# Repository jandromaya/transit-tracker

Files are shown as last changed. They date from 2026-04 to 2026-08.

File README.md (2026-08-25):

# transit-tracker
This is a personal transit tracker project for CTA buses and trains.

Status: v1 complete!

[Video of v1](./documentation/video.mov)

## Requirements

**Hardware**

2 64x32 LED matrices

Power supply

Connector (right now need the special one for the matrix, soon just a USB-C)

You also need to get the PCB. Using the gerber files in this repo, you can get the PCB manufactured at your preferred PCB manufacturer (I used PCBWay).

## Installing/Building

(These instructions reflect the set-up process as of August 24, 2026.)

### Getting API Keys

Before you start connecting or building anything, you need to have API keys for CTA trains and buses. You can get those here:

Buses: https://ctabustracker.com/account

Trains: https://www.transitchicago.com/developers/traintrackerapply/

Once you have your keys, pull this repo. Inside the `include` folder, make a `secrets.h` file and place your keys in there, like this:

```
#ifndef SECRETS_H
#define SECRETS_H

#define TRAIN_TRACKER_API_KEY "Your key here"
#define BUS_TRACKER_API_KEY "Your keky here"

#endif
```

Now you're ready to build

### Building the tracker

1. Connect LED matrices together with HUB75 cable

2. Connect the PCB to a computer and flash the PCB

   1. Open VS Code, navigate to the project folder, and run idf.py flash

3. Set the tracker configuration

   1. Run idf.py menuconfig from the project folder

   2. In the menuconfig menu, navigate as follows:

      1. Component config->WiFi STA Configuration

         1. Check connect using wifi
         2. Set WiFi SSID and password

      2. Component config->HUB75 RGB LED Matrix Driver

         1. Go to Board Preset and check Manual Pin Configuration

         2. Go to Panel Settings and set the following settings:

            1. Panel Width: 64 (pixels)
            2. Panel Height: 32 (pixels)
            3. Minimum Refresh Rate: 60 (Hz)
            4. Default Brightness: 128

         3. Go to Multi Panel Layout and set the following settings:

            1. Layout Rows: 1
            2. Layour Columns: 2
            3. Layout Type (Horizonal (Single Row))

         4. Go to Pin Configuration and set it as follows:

            ```
            4 - R1
            5 - G1
            6 - B1
            7 - R2
            15 - G2
            16 - B2
            17 - A
            18 - B
            14 - C
            13 - D
            -1 - E
            11 - LAT
            10 - OE
            9 - CLK
            ```

      3. Component config->Transit Tracker Configuration

         1. Check connect using wifi
         2. Check enable bus tracking if you want to track buses
         3. Check enable train tracking if you want to track trains
         4. Hit enter on bus routes to track, and enter the numbers of the buses you want to track
            1. i.e., if you want to track the 1 and the 7, type in `1,7` with no spaces just like shown
         5. Hit enter on bus stop IDs to track, and enter the number of the stop IDs you want to track
            1. i.e., if you want to track stop 68 and stop 1583, type in `68,1583` with no spaces as shown
         6. Hit enter on "Max number of bus predictions to receive," and enter the maximum number of bus predictions you want to display
            1. I recommend 6 or 9
         7. Hit enter on train stop IDs to track, and enter the number of the stop IDs you want to track
            1. i.e., if you want to track the Roosevelt and the Jackson stops, type in `41400,40070` with no spaces as shown
         8. Hit enter on "Max number of train predictions to receive," and enter the maximum number of train predictions you want to display
            1. I recommend 6 or 9

4. Connect the PCB to the matrices with the HUB75

   1. Note: the HUB75 header in v1 of the board is wired wrong, so you have to pull the header pins to the opposite side of the board for it to work. I plan to update the board so this is no longer an issue.

5. Connect the matrices' power leads to the screw terminals on the PCB

   1. Power is closest to the HUB75 header
   2. GND is the other terminal

6. Print the enclosure

   1. Files in 3dprinting folder of this repo

7. Screw PCB to the thin part of the enclosure

   1. There are little holes for screws to go through on both the thin part of the enclosure and the PCB
   2. With v1 of the enclosure/board, the PCB ends up a little tilted when you do this. This is something I plan to fix with the next version

8. Place both parts of the enclosure on top of the LED matrices, and screw them together using the screws that came with the LED matrices

9. Connect the train tracker to wall power using a USB cable

10. Watch your trains/buses go!

### Libraries/Skills used

C, C++, ESP IDF/FreeRTOS, LVGL, PCB Design, CAD (Autodesk Fusion), 3D Printing

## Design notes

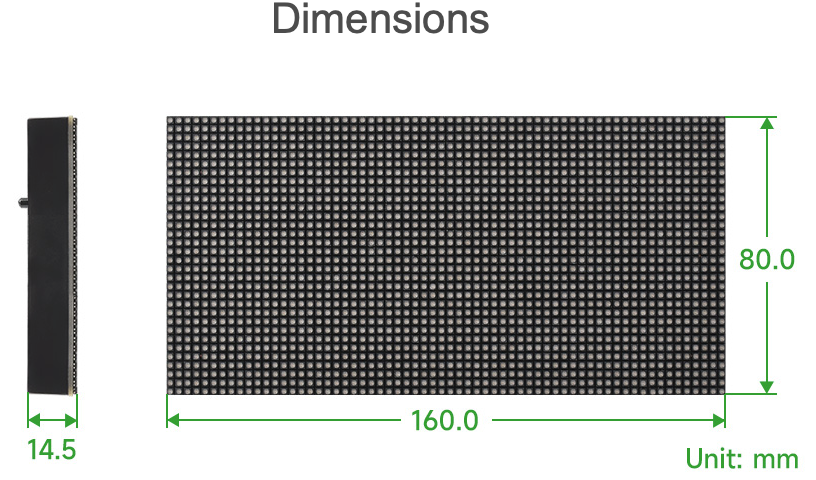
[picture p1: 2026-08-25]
documentation/images/2AUG25_5.JPG.png

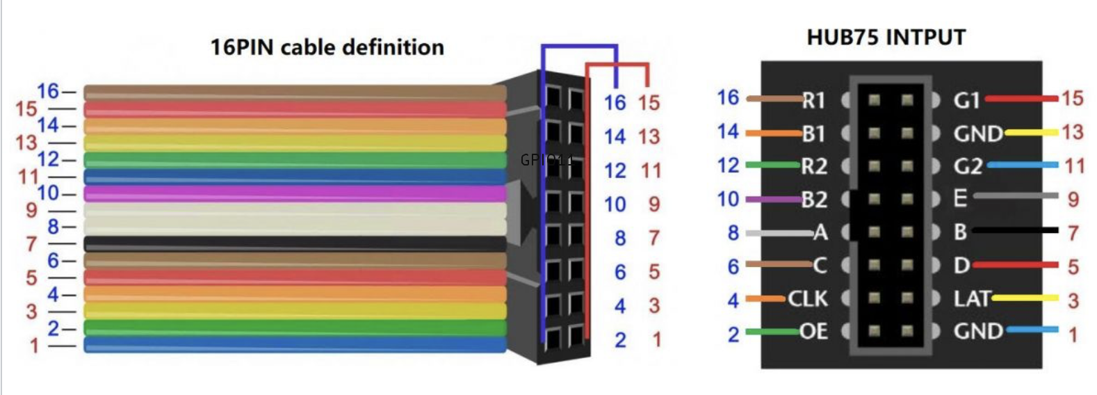
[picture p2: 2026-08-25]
documentation/images/hub75.png

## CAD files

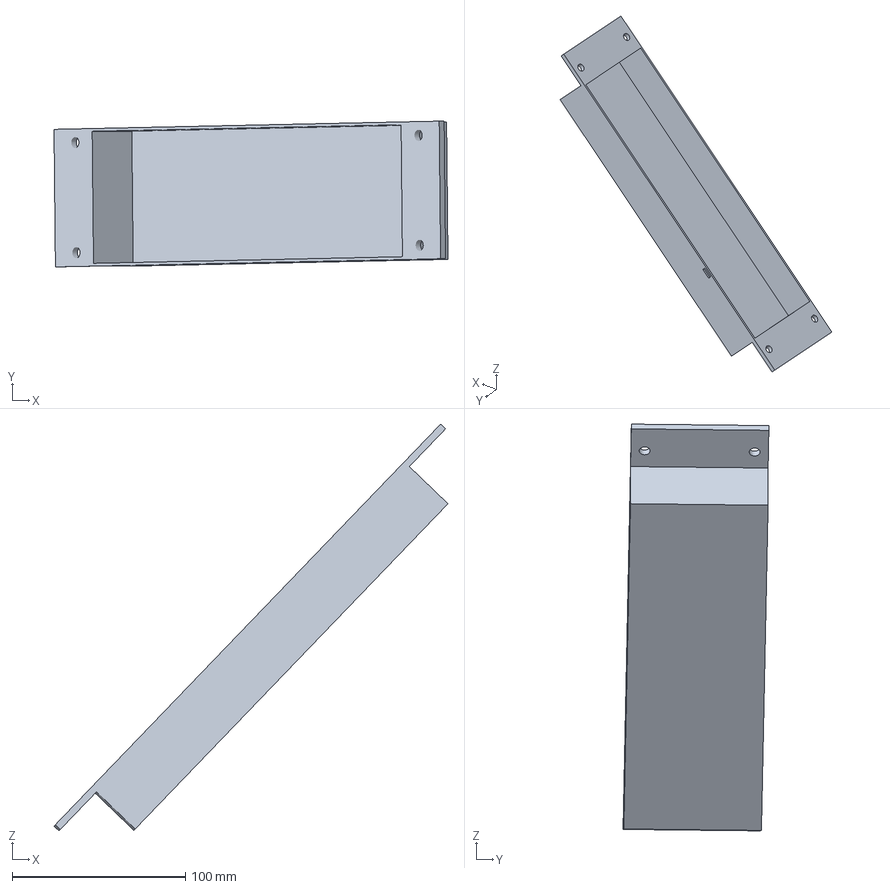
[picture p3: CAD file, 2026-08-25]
3dprinting/Transit Tracker Enclosure Hollow Part.3mf
227.3 x 84.1 x 234.7 mm

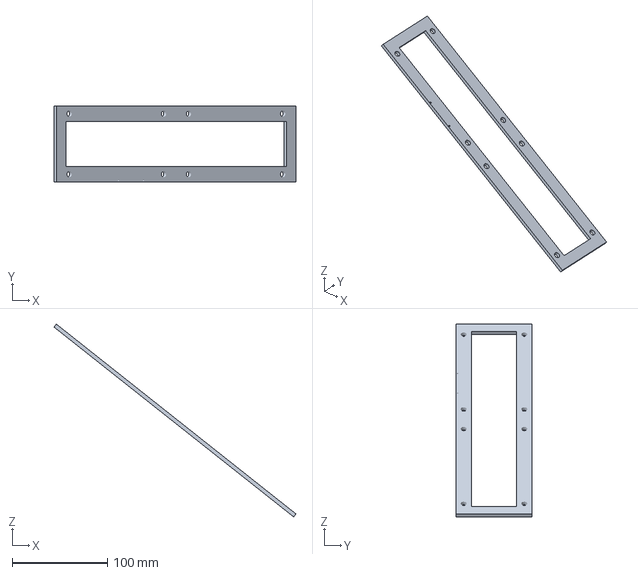
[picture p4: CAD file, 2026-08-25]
3dprinting/Transit Tracker Enclosure Thin Part.3mf
253.8 x 79.4 x 202.2 mm

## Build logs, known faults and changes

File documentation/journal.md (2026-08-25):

# Train Tracker journal
This is an engineering journal for me to document my progress. I don't know how much I will actually use this thing, but hopefully I stick to it.
## Mar 22, 2026
Today I started actually working on this project because I want to seriously commit to it. I have been thinking of making a transit tracker screen for a while because I think it would look cool and it sounds fun.

As of now, I have just gotten my API keys from the CTA website and I started this repo. I added some things to do in todo.md (although I should add some stuff about researching hardware to buy on there), and that's kind of all I have done for this today.

This is my overall game plan:
- Read API docs to get a rough idea of how the API works
- Make a prototype program that just prints bus/train info to the command line from an ESP32
- ^ while I build this, order some hardware (preferably one of those large LED matrix screens, as that's kind of like what the CTA uses)
- Once I get the prototype built okay, try connecting it to the LED matrix screen to display output on there
- Once I am happy with the output on the LED matrix screen, design a PCB for the circuit
- test PCB
- once I am satisfied with PCB, make an enclosure for whole thing

Excited!

## Mar 23, 2026
Okay, today I began looking at LED matrix options. This one looks good:
[Adafruit](https://www.adafruit.com/product/5036)
[AliExpress](https://www.aliexpress.us/item/2255799816372142.html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)
[Waveshare](https://www.waveshare.com/rgb-matrix-p2.5-64x32.htm?sku=23707)
It has its own library that I can use to control the matrix, and you can link multiple together. The linking together seems useful, so I *may* want to do it, but I think I could maybe get away with just using one of them. I guess the design trade off would be that I can show more information with two matrices linked together (i.e., stop names), but since I know exactly what stops are near my house for what routes, I don't know if I *need* to link two of these.

To connect the matrix to a board, I need a 16-pin IDC connector, like this one:
[DigiKey](https://www.digikey.com/en/products/detail/molex/0702461601/760169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)

To power the board, Adafruit suggests using using their [wall adapter](https://www.adafruit.com/product/1466) and [2.1mm jack](https://www.adafruit.com/product/368).

This [other transit tracker project](https://transit-tracker.eastsideurbanism.org/docs/build-guide/materials#note-about-displays) uses just a [USB power supply](https://www.adafruit.com/product/1994) and a [USB-C cable](https://www.adafruit.com/product/5031).

So all together I think that's all the hardware that I need  to connect the matrix to an ESP32.

---

Ok that was this morning, tonight I set up the file structure for esp idf and I will read some of the api docs before I go to bed. 

## Mar. 24. 2026

Today I:

- went through and annotated the bus time API, gonna read the other one later (maybe omw to work)
- Went through the train time API (I did do it omw to work and also before bed lol)

As far as the bus time API goes, it looks like the main thing to worry about is just "predictions" and probably delays/cancellations (which are part of the dynamic action types). I highilighted the relevant fields of the output that I need to worry about in my local copy of the document. I'll need cJSON.

for the traintime API, it looks like the "Arrivals API" from page 5 will be the most useful. Appendix D also has useful information on how to turn this output into "minutes until this train arrives".

## Mar. 26, 2026

Yesteday and today I started coding up some basic programs, just getting the ESP32 connected to Wi-Fi and sending https requests and messing around with different things along the way. 

At first I was messing around with FreeRTOS tasks and semaphores, then I was using task notifications. Turns out I don't think I'll really need any of that, but it's in the code at the moment because that's just what I was trying out.

Right now, the ESP32 can get predictions of routes. From here, I need to parse the JSON responses so that the output is actually usable. I also will need to get multiple routes at once (which I'm pretty sure I can just do with the API).

## Mar. 30, 2026

I am travelling right now but I have continued working on this whenever possible. Here are a few design things I have been thinking about:

### Design thoughts

**General flow of the program**

- 30 second cycles
- 24 seconds
  - Output routes 
  - This seems kind of long, but depending on the number of routes you are retrieving you may have to scroll to get through all of them
    - Could be three screens of routes, each shown for 8 seconds for example
- 3 seconds
  - Output current time
    - Can just get this from CTA API or with SNTP
  - Could probably be taken out, but I just think it would be useful
- 3 seconds
  - Output other info
  - Maybe just "CTA tracker" or if there are different modes, maybe just the name of the mode

### Considerations/Edge cases

- Outdated predictions
  - Sometimes prediction timestamps are outdated (i.e., don't match the current time in the CTA system)
  - May want to check that the predictions have a timestamp within a threshold amount of time from the current time
- May want to consider dynamically allocating memory in perform_get_request()
  - if so, make it caller-owned
- What priority should the parsing task have?

## Mar. 31, 2026

Worked on this a little bit today. I updated the parse task to handle http responses from different sources, and right now it handles data from the bus prediction task and the get time task, printing the received data to the console with printf.

In the future, I want to mainly do two things:

1. Add the train data
2. Add some filtering of what to show on the display (for example, if a response's timestamp is too old, it should not show)

Once this is all handled, the minimum API side of the project is pretty close to being done I think. For a basic proof of concept, all I need to do now would be connecting all this stuff to an external display and printing

## Apr. 1, 2026

Okay, so I have been thinking a bit more about what I need hardware-wise, as I realized my earlier parts list is not great. Adafruit offers [this breakout board](https://learn.adafruit.com/adafruit-matrixportal-s3/pinouts) for ESP32 matrix control.  The breakout board itself is out of stock, but I can take the components and make my own thing. Here's what I need (based on what they have on this board):

| **Part** | **Quantity** | Unit **Price** | **Total Price** | **MPN** | **Link** |
| --- | --- | --- | --- | --- | --- |
| LED Matrix | 2 | 17.99 | | RGB-Matrix-P2.5-64x32 | [Waveshare](https://www.waveshare.com/rgb-matrix-p2.5-64x32.htm?sku=23707) |
| HUB-75 Socket (maybe a 2x10) | 1 | 1.09 | | S6106-ND | [DigiKey](https://www.digikey.com/en/products/detail/sullins-connector-solutions/PPPC102LFBN-RC/807245) |
| Level shifter | 2 | 0.95 | | ahct245 | [DigiKey](https://www.digikey.com/en/products/detail/texas-instruments/SN74AHCT245N/277122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) |
| USB-C Power Supply | 1 | 7.95 | | 1994 | [Adafruit](https://www.adafruit.com/product/1994) |
| USB-C cable | 1 | 5.25 | | 5031 | [DigiKey](https://www.digikey.com/en/products/detail/qualtek/3021107-01M/13181649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) |
| 2x8 IDC Cable | 1 | 1.95 | | 4170 | [Adafruit](https://www.adafruit.com/product/4170?srsltid=AfmBOorfjdOh5D1p04Qbc45afL_Oq-bk-VF9IhERsBwBOS83qW3fk6iHNpM) |
| HUB-75 Plug | 1 | 0.32 | | S9171-ND | [DigiKey](https://www.digikey.com/en/products/detail/sullins-connector-solutions/SBH11-PBPC-D08-ST-BK/1990064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) |

Some thoughts:

- Power
  - On the breakout board, they power the matrix with the USB-C port
    - The USB-C port connects to two M3-threaded screw terminals
  - ESP32 seems to be powered with either JST connector or USB-C 
- HUB-75 connector
  - On the breakout board i put up there, they use a 2x10 instead of a 2x8. not totally sure why, but maybe it's helpful
  - Also, you could either have a socket here (i.e., a female connector) or a plug
    - If you have the plug, then you need to buy an IDC cable to connect to the matrix
- Multiplexer type thing
  - AHCT245
  - These were included in the adafruit breakout board I found
  - What are they?
    - **8-bit Octal Bus Transceiver**
  - Why do they use it?
    - Level shifting
    - Basically, the ESP32 is going to output at 3.3V, but the matrix needs input at 5V. This specific device helps bridge that gap
  - UPDATE, it actually works ok even if you don't use these. More details on apr. 16

## apr. 6, 2026

Today I filled in the table above and bought everything. Exciting!

^ that was in the morning.

I added some (very basic) train API functionality. It's basically just performing a get request and outputting the response. Some next steps would be to format the reponse a little more (i.e., in countdown format like the buses). I also need to add my own logic for delays/DUE notifications because the train API doesn't do this automatically like the bus one.

I was also thinking... It may be better to delay the different tasks relative to each other rather than having the big offset at the beginning I currently have. Think about this more.

Regardless, I think my task scheduling may be a little messed up. The train task doesn't seem to be executing as often as I intended. Look into this also.

## Apr. 7, 2026

I woke up a little bit ago and started working on this. I fixed the task scheduling issue I noted above (the train task said`vTaskDelay(10000)` instead of `vTaskDelay(pdMS_TO_TICKS(10000))`).

I began formatting the train API responses a little bit by making the `print_train_info` helper function. Right now, the function outputs if a train is due or if there is a delay. I still need to figure out how to format the string predictions into a countdown. 

Here are some solutions:

- could I change the strings into unix time and compare them that way? this seems like easiest option
  - can use strptime to convert the string to a tm struct, then use mktime to convert the tm struct to unix time
- I could compare each part of the string to see what is different, but this seems overly complicated

Here are some edge cases to think about:

- what happens if current time is before midnight and next train comes after midnight
- what happens if time difference is negative (I think this shouldn't happen, but I didn't read any guarantees of that in the API guide)

## Apr. 8, 2026

I was going to work on the stuff above, but I realized that I could simplify what I already have a little bit.

I realized that right now I have three tasks that basically do the same thing because I was just coding and trying stuff as I went along. Instead of doing that, I think it may be simpler and more useful to have a generic get request task (`vPerformGetRequestTask`) and a separate request scheduler task (`vRequestSchedulerTask`. 

`vRequestSchedulerTask` could send `RequestType_t`  variables to the `vPerformGetRequestTask` using a queue. Based on the request type, `vRequestSchedulerTask` can use different URLs to make the correct GET request.

One more thought: how do you get the URL?

- Could be handled by the `vPerformGetRequestTask`
  - Would mean having some sort of if statement to decide the type of request received
  - feels more messy
- Could be handled by `vRequestSchedulerTask`
  - Would pass the URL on the queue, can be done with existing QueueData_t struct

I think I'll go with second option

## Apr. 9, 2026

Okay today I'm actually gonna work on the train formatting. Here is the output of the API:
2026-04-09T07:32:07

I need to turn this into unix time first and then compare the two values. Here's how to use [strptime()](https://pubs.opengroup.org/onlinepubs/007904875/functions/strptime.html).

%Y-%m-%dT%T

I did it! 

## Apr. 14, 2026

All the parts finally arrived today, starting to assemble...

I may have run into some issues with powering the matrix, but we will see

## Apr. 15, 2026

Today I used the matrix for the first time! Everything seems to work okay. There's a few pixels near the bottom right on one of the matrices that flicker a little bit, but I may need to do some more extensive testing to figure out what is going on with that. 

Here's a picture:

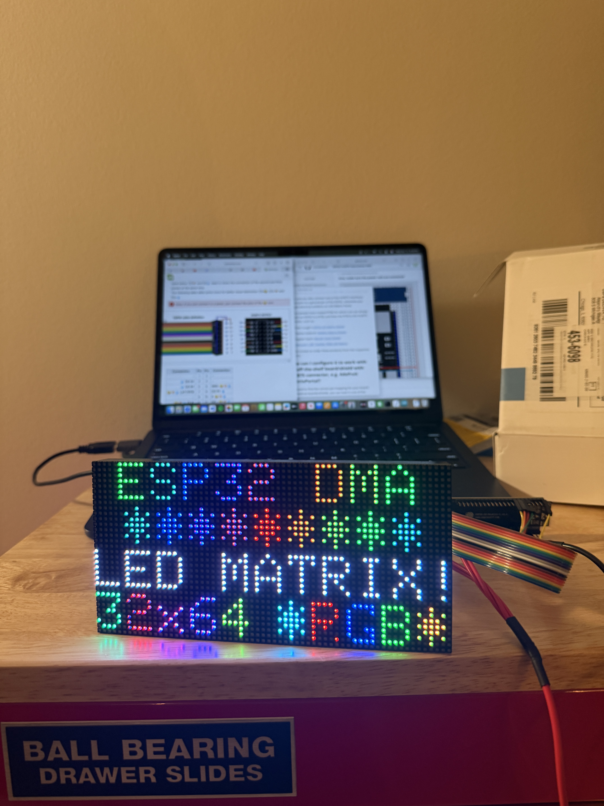
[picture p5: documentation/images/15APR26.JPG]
Image of LED matrix


For next steps, I should get more familiar with the library and read about how it works:
https://github.com/mrcodetastic/ESP32-HUB75-MatrixPanel-DMA

## Apr. 16, 2026

I'm starting to read some more about the library/matrices.

I realized that the matrix worked well even without the AHCT245s for level shifting. Based on what I have read, this isn't really supposed to happen, but the ESP32 GPIO alone (which outputs at 3.3v, not the 5v expected by the matrix) could power all the red lights on the matrix without connecting the matrix itself to power. I will try using the AHCT245 to see if I notice a difference. 

As far as the flickering issue I noted yesterday, it seems that the creator of the library I used to test recommends [connecting a capacitor on the panel's VCC and GND](https://github.com/mrcodetastic/ESP32-HUB75-MatrixPanel-DMA/issues/39#issuecomment-720780463) 

Additionally, right now my ESP32 and the panel were connected to different grounds (the ESP32 connected to my computer, but the panel connected to wall power). That could also be the culprit of the flicker.

## Apr. 17, 2026

I found a different library that works with ESP-IDF. Here it is: https://github.com/esphome-libs/esp-hub75

I decided to swtich because the other one just used arduino elements under the hood even within ESP IDF, and that just seemed a little inefficient. I began using some of the example documentation and it seems to work. I'll need to do some more testing tomorrow.

Quick thing: draw.fill() seems to map to RBG instead of RGB on this matrix (I think I read something about it in the Adafruit documentation actually)

## Apr. 18, 2026

Today I did a lot of work figuring out how to use LVGL and the library I found yesterday to display stuff on the screen the way I want to. Here's what I have (it looks like it actually displays bus data, but that's just hard coded right now):

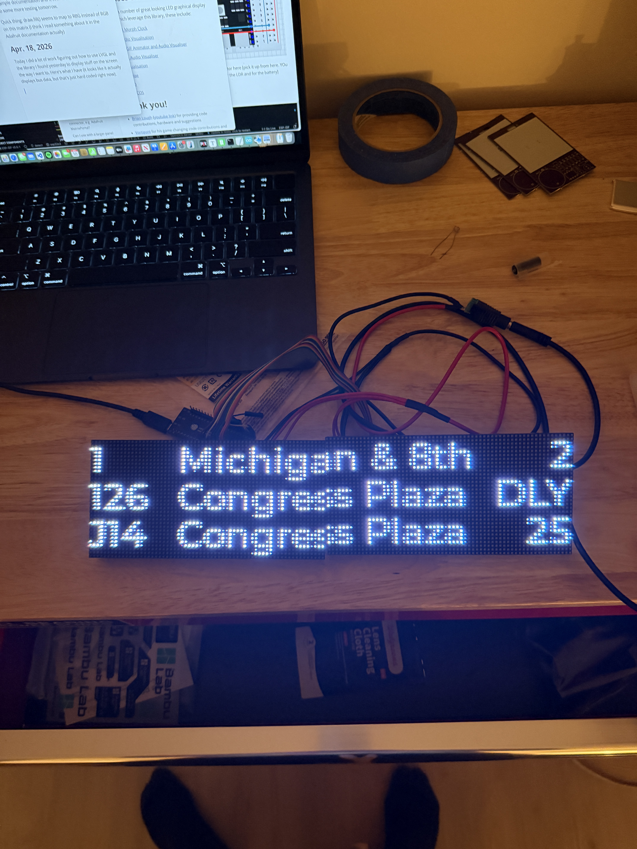
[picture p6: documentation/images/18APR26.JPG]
LED Matrix


The middle two rows scroll if they are too long, and I have set it up to update the text. Now I just need to combine this with the actual bus data stuff

## Apr. 19, 2026

Today I got the matrix to print real bus data! Right now it's kind of in a prototype state, as it only prints 3 buses out and nothing else. From here, I need to make it print more bus data and probably clean up the code a little bit.

## Apr. 20, 2026

Re: more bus data and cleaning up the code

I think it may be useful at this point to set up a Kconfig file for settings related to the bus URL (max num buses wanted, routes, etc). Later on, I want to make this info controllable with a website, but I think it will be good for now to set up the Kconfig file

How do I add support for more output?

- Right now, it just outputs 3 bus routes, but I want to output more bus routes and also potentially output train routes/the current time
- I have come up with two ides for how I could implement this with LVGL:
  - Scroll method - everything is one LVGL screen, and whenever I want something to show, I just scroll to it
    - Pros
      - Less screens to deal with
      - Could mix train and bus info if that is desired
      - Could show less blank lines potentially (I can just scroll in such a way that there are no blank lines)
    - Cons
      - Unsure how I would implement the time display
      - The look is less deterministic (will depend on how many items are on screen)
  - Active screen method - There are mutliple screens for buses and multiple screens for trains, and I just switch between them to output different content
    - Pros
      - More uniform look
      - Can just implement the time display as a separate screen
      - Seems like how you're probably meant to use LVGL tbh
    - Cons
      - Feels harder to implement (if i receive less data than the max, how do I make sure no blank/outdated screens display?)
      - How do I figure out how many screens to display?

I'll try the second method. Here's what I think I need to do:

1. Set up a screen array of size `ceil(CONFIG_TRACKER_BUS_TOP/3) + ceil(CONFIG_TRACKER_TRAIN_MAX/3)`
   1. This is the max number of screens I would need
   2. Can add an extra screen if I want to display the time
   3. I may want to set a maximum number of total screens (which would mean a max number of top/max). This could be determined by memory constraints
2. For each screen, I'm going to want labels
   1. One for each position on the screen (9 for trains/buses, just 1 for the time)
   2. I could do this in a struct, so the screen array would be an array of structs, inside the struct would be the `lv_obj_t` for the screen and and the `lv_obj_t` array for the labels 
3. in the main task
   1. I send messages to the bus, train, and time queues to send GET requests
   2. The Parse task should populate the labels/screen/struct or whatever and tell the main task how many predictions it parsed
      1. This is probably best done with a queue
      2. It should also zero out any extra space in screens
   3. Once the main task knows how many predictions were parsed, the main task can switch between the appropriate amount of screens
      1. the number of screens is just equal to `ceil(parsed_tasks/3)`
      2. how often should it switch?
         1. This could be set by the user in Kconfig or
         2. it could be decided based on 30 second intervals: we have 24 seconds for bus/train times (12 for bus, 12 for trains). If there are 4 train screens to switch through, then each gets 3 seconds, etc
4. I would need to initialize all this also
   1. I think I can do this in the lv_ui function

## Apr. 23 2026

Today I made some good progress on this. I basically got up to step 3 above. For tomorrow:

figure out a good way to let hte main task know how many predictions were parsed and to then sync. I was trying to use task notifications, but I think I may just have to use an event group and a global variable

## Apr. 24, 2026

Lots of progress today. It now prints out several screens of bus predictions. To implement it, I ended up using an event group and a global variable like I said above. 

From here, some to-dos:

- clear old predictions from active screens
  - For example, if I get one API response with 6 predictions, that fills up two screens completely. Later on, if I get an API response with just 5 predictions, that SHOULD have screen 1 with 3 predictions and screen 2 with 2 predictions, but currently, I don't clear old predictions, so screen 2 shows the 2 new predictions but it will still display the old prediction at the bottom
  - using the num_predictions variable, I can determine which rows need to be cleared on the display
    - max_predictions - num_predictions = rows_to_clear
    - where max_predictions = num_screens * ROWS_PER_SCREEN
    - and rows_to_clear tells me how many rows to clear on the last screen (should just be 1 or 2 rows)
    - this could be done in the main task or the parsing task. right now leaning to doing it in main task to limit parsing task's job to just parsing, not displaying
- eventgroup solution is currently a little janky
  - sometimes the time out doesn't leave enough time for the parse task to complete and set the event group bits
  - I could just set a longer time out
  - but the truth is that the main task is calling eventgroupwait() right when the GET request task runs, so there needs to be enough time for both the request task and the parse task to run or the main task should wait until BOTH the request task and the parse task finish (which could just be implemented using the current event group lol)
- need to update function comments because some things have changed

## Apr. 26, 2026

I fixed most of the things above (I have not updated the function comments because I'm still messing with those)

Now I need to think of how to integrate trains predictions into the system

The overall flow is simple:

1. Get bus and train predictions
2. Print the predictions

I need to consider a few things:

- do I get all the predictions at the same time and then print them? OR do I get and print bus predictions and then later get and print train predictions
  - The former may be more consistent, but may not always show the latest data, while the latter will always show the latest data but may get caught up with the GET requests
- Do they all share one screen array?
  - i think lowkey no
  - it will be easier to manage if there is a train screen array and a separate bus screen array
  - also avoids race conditions if i want to implement concurrency later (which I think may be a good idea)

Ok it's not the end of the day. I went through and created a new screen array for train screens and added a new funciton for screen creation. 

Tomorrow I should try to actually get things printed on the screen (start by modifying the print_train_info funciton)

## Apr. 27, 2026

I did it! It now displays information for both trains and buses

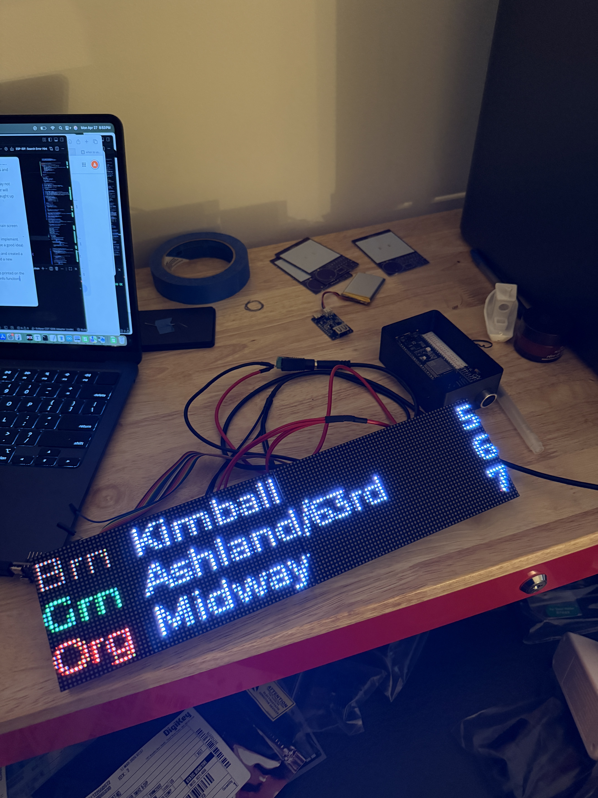
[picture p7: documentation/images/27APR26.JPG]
Tracker displaying train times


Now I should clean up the code and add more robust error handling. I'm also considering how I display trains. Right now, it obviously doesn't show what train stop the prediction is for. While clearly this is important info, I think it would make the display overly crowded (and realistically, I will know what station the predictions are for lol)

Now that I am thinking about it, I don't really show direction info for buses either...

I think to show this info, I could do the following

- trains
  - [Red] [Harrison to Howard] [Min]
  - [Color] [Station to Destination] [Min]
- Buses
  - [Route] [Direction - Stop] [Min]
  - [1] [N - Michigan & 8th Street] [Min]

Okay I did this. The buses work pretty well, but honeslty the trains are hard to read. I think I'm gonna keep the direction for the buses but not the trains for now. A potential solution for trains is showing the display like this:

[Station to Destination] [Min], where [Station to Destination] is in the color of the station

This would require a new label set up for trains, though (which I think is fine)

I'm gonna start experimenting with this later. for now, I'll keep trains directionless and buses with direction.

## Apr. 28, 2026

It's the morning right now. I started messing around with the new train layout a little bit, but I realized I'm gonna need a slightly bigger overhaul than I thought yesterday night. 

Basically, I would need to have different size `label_array` variables for the bus and the train screens. This shouldn't actually be too bad; I would just have to modify `create_screens` and probably add separate `COLS_PER_ROW` macros for buses and trains.

Additionally, I'll need to modify the `lvgl_ui` function to make train and bus UIs. 

## Apr. 29, 2026

Started work on ^ today. So far, I updated `lvgl_ui` to handle both bus and train UIs. Now I need to change how it is actually used inside `create_screens` in main.

I did it! The train displays now show route, station, direction, and prediction!!!

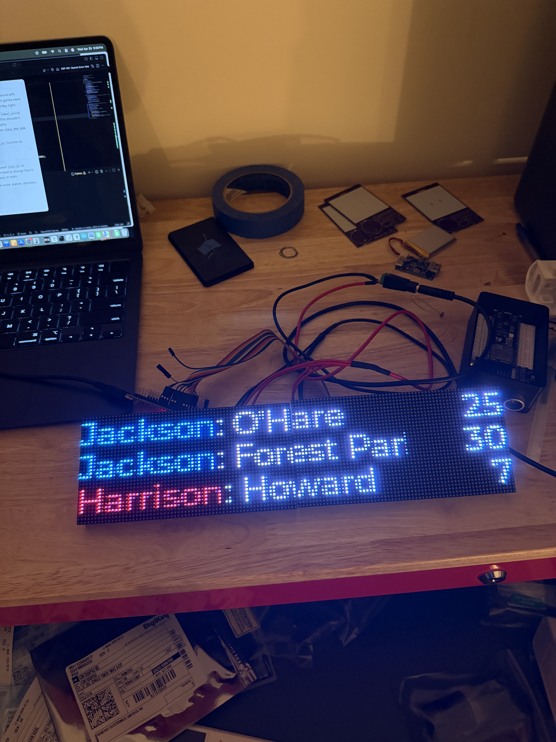
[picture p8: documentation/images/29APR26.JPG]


tomorrow i should start cleaning up the code 

## Apr. 30, 2026

I started cleaning up the code as promised. I added several helper functions, and now app_main() is much easier to follow. It also handles failed GET requests a lot more gracefully now and handles some issue with train prints better.

## May 3, 2026

I'm starting to work on the PCB! I'm working through a video by predictable designs and looking up stuff as I go along. So far I figured out that I'll need a TVS diode by the USB port. It basically just protects from power surges. If it detects a power surge, it shorts the signal down to ground. 

I was thinking I would need one to protect the esp32s3 and a separate one to protect the matrices (because they operate at a higher voltage). Now that I'm thinking about it, though, I have been using these matrices with no such protection for a while and it has been fine, so I think I'll just keep following the tutorial and re-visit the TVS for the matrices later. For now, I will plan on just using one with the esp32

[This link explains more about TVS diodes](https://solutions.mccsemi.com/understanding-tvs-diodes-a-comprehensive-guide)

## May 4, 2026

Today I'm still chugging along on the predictable designs tutorial

https://docs.cirkitdesigner.com/component/885af448-2bdb-49bc-ae1b-0e781522c801/hub75

## May 31, 2026

It's been a second since the last time I wrote here. I took a semi-forced break for ~2 weeks because I went to see my brother and friends graduate college. I returned a week ago, and I have been working on the project during that time (just not documenting on here).

During that time I didn't document, I was mainly troubleshooting some hardware issues. I realized that I should test out the level shifters on the breadboard before trying to add them to my PCB design. I thought this would be pretty simple, but it turned out to be a bit of a challenge.

Wiring everything together with my jumper cables was messy, but I didn't have a better option, so I had to wire and re-wire things several times. I also had to dance around several pin layouts because they interacted with different options on the board (for example, I was using pin 38 for a second to drive parts of the LED matrix, but I forgot that pin 38 also drives the built-in LED on the ESP32). In hindsight, I should have just planned my pin layout BEFORE wiring things, but you live and you learn!

It also turned out that one of my esp32s has something wrong with it. I wired everything correctly, but the green output kept not working (it seemed to just be floating no matter how I wired it). After switiching to a fresh esp32 I had lying around, everything seemed to work fine.

Now it works, though, and I'm ready to do more serious work on the PCB. 

## Jul. 30, 2026

I fell off of writing on here, but the PCB just arrived!!!

Lessons learned:

Mark ground and power for connections to any external devices (thankfullly I figured out that I needed to check this before connecting anything, but for future reference. This could really mess things up obv)

***THE SCREW THING CLOSEST TO THE HUB75 CONNECTOR IS POWER, THE ONE CLOSEST TO THE LED IS GROUND***

Ok, so the ESP32 flashes fine and seems to run fine

Powering the LED matrices through the PCB doesn't seem to be working

- When I connected the matrices to the power on the PCB, no lights came on, but connecting the matrices to power through the wall adapter directly turned some lights on

Something seems to be off about the HUB75 connections

- The display just has some lights on but is not showing anything
- SCRATCH THIS. IT WORKS FINE. THE ONLY ISSUE WAS THE HUB75 CONNECTOR

The power thing is most likely just a hardware issue I can't fix without a new PCB, so I'll try fixing the hub75 issue (because I think I can fix that with software)

- my pin configuration seems correct
- i'm worried dthat the pins on the hub75 connector don't line up the way i believed/that I did it wrong
  - Update, yeah I think I fucked up
  - It looks like I messed up the orientation of the hub75 during wiring. still confirming this.

### Identified Issues with PCB

#### ISSUE 1: Wrong HUB75 orientation

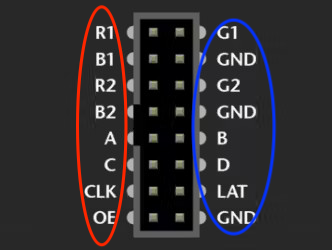
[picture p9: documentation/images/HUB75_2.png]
1. 
2. On the PCB, i made the connections as if the red row was in the place of the blue row.
3. Because the GND pins are hard-wired, I can't just change this in software unfortunately :/

**One POSSIBLE solution**

I *could* fix this if i finmd a way to connect the plug backwards

it only goes in one way, but if i can break the plug a little bit it could work

I can also just try to de-solder and solder it back on the other way

## Aug. 2, 2026

### My fix for the issues from Jul. 30

My diagnosis of the issue was correct. To confirm my theory, I wired it using jumper cables temporarily like this:

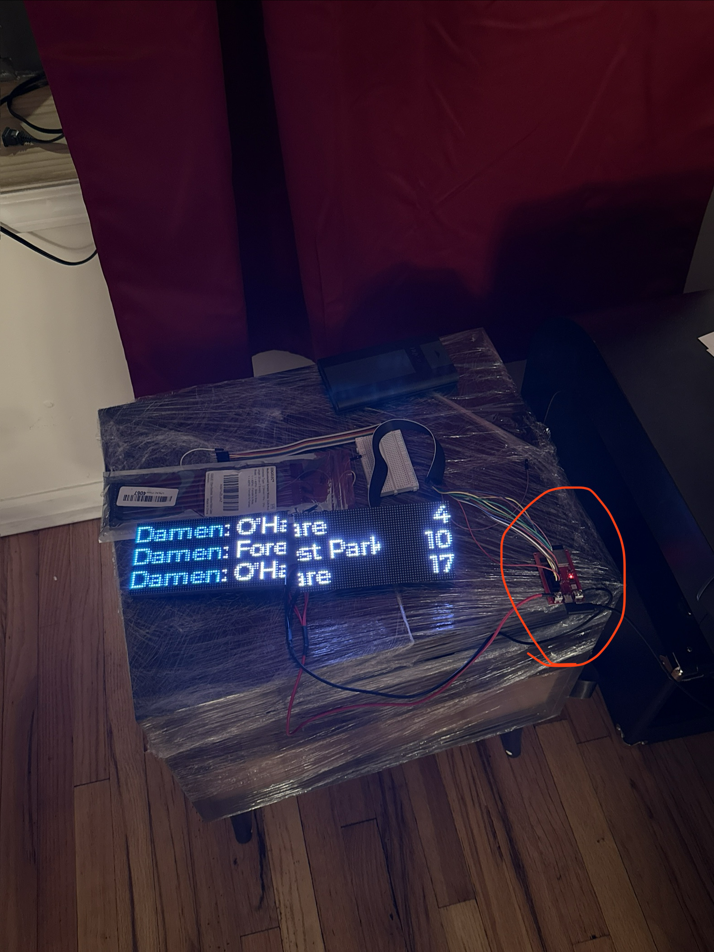
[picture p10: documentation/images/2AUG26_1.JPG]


I connected each prong of the HUB75 connector into its correct spot on the IDC female header using jumper wires. After I did this, the whole thing worked well, proving that the issues came from the HUB75 connector's orientation.

To fix the issue, I first tried to de-solder the whole connector and re-solder it on the back side of the board. De-soldering the whole HUB75 connector turned out to be really hard. First I tried to wick away as much solder as possible and then melting the soldered connections while pulling on the connector to remove it from the board. I got it to move a little bit, but progress was slow and difficult. 

After that, I tried adding a lot of solder so all the prongs connected, heating up all of them at once and pulling on the connector. At first, this worked a little better (and I think it would work on smaller/less clunky connectors), but after a while I just created a huge blob of solder on the other side of the board, so I aborted.

FINALLY, I decided to just push the connector's pins from one side of the board to the other. To do this, I first clipped away the plastic casing of the connector. Then, pin by pin, I heated the joint, melting the solder, and pushed the pin to the other side. Once that was done, I removed excess solder, and re-soldered any joints that looked weak. Here is what the board looked like in the end:

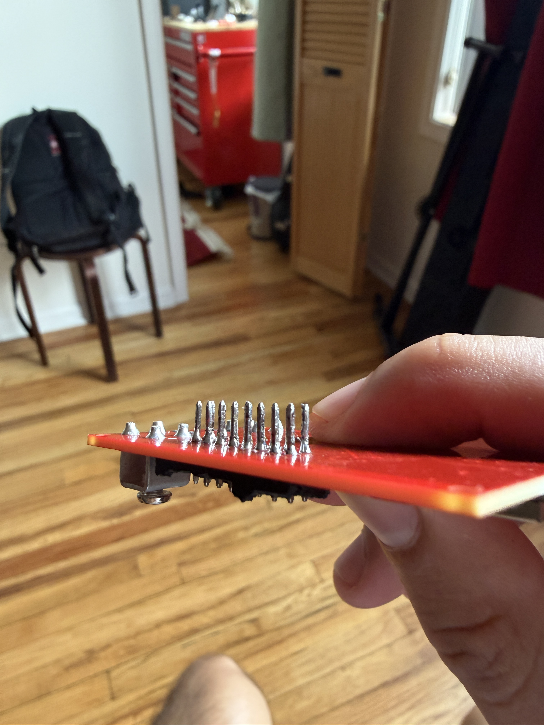
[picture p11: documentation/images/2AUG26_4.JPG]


And now here is the board connected to the matrices and displaying transit information:

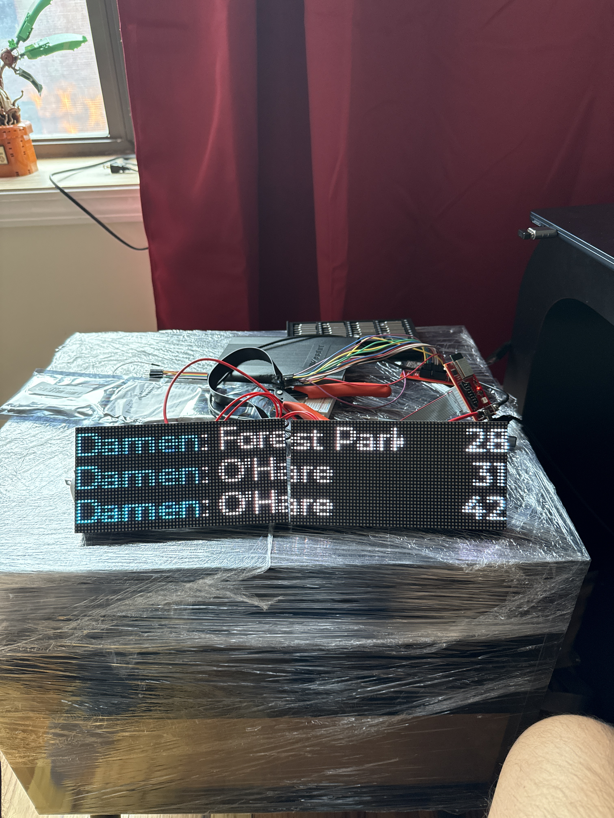
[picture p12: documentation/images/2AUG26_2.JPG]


Finally, here is a closeup of the connection between the board and the IDC cable (you can see the old board near the top of the photo with the jumper cables still connected and the new board closer to the bottom connected directly to the IDC cable):

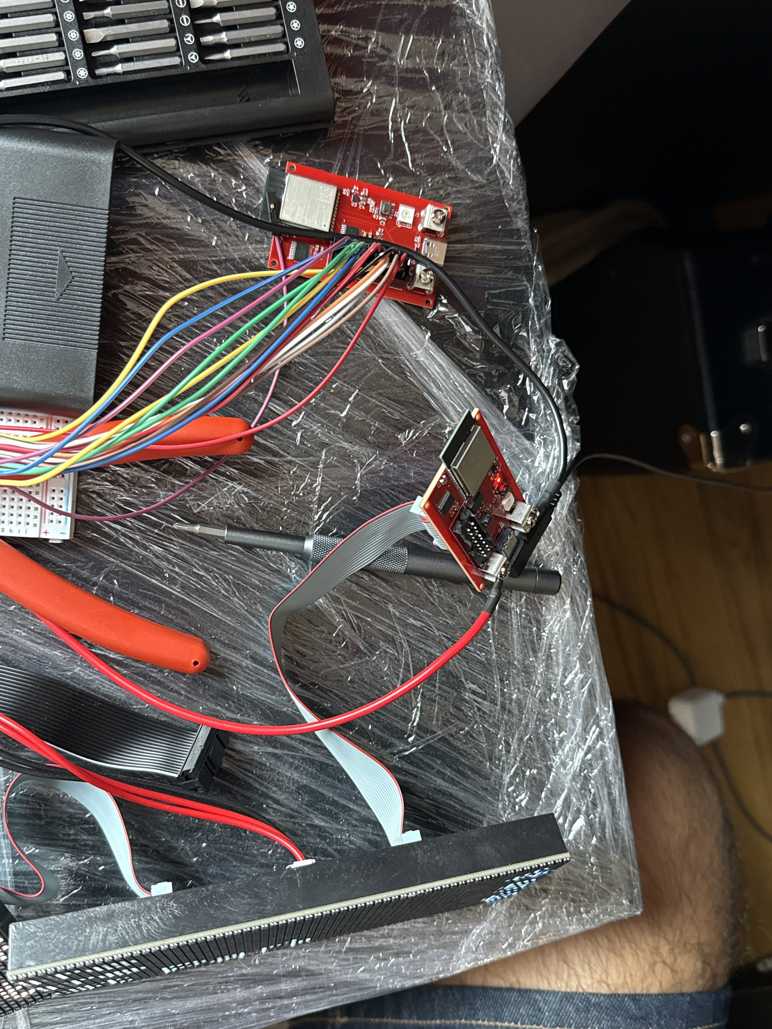
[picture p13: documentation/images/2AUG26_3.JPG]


Now my plan is to make an enclosure for this thing. I should also update the PCB design in case I want to make more.

### Updates to make for the PCB design

- Add POWER and GND symbols for the spade connectors that power the matrix
- Re-wire the HUB75 connector the right way
- Maybe add a button or something that you can access from outside the enclosure

### Also, here is the final pinout:

4 - R1

5 - G1

6 - B1

7 - R2

15 - G2

16 - B2

17 - A

18 - B

14 - C

13 - D

11 - LAT

10 - OE

9 - CLK

## Aug. 4, 2026

### Enclosure Considerations

- The back should be flat for easy wall mounting
  - At least have a signfificant falt portion
- The enclosure should be easy to disassemble
- The enclosure should be able to stand on its own (for cases where you don't want to mount to a wall)
- The enclosure should be slim
- The USB port shoud be accessible without opening the case

## Aug. 24, 2026

Today I can say I finished v1 of this project! It took me a while since the last update becuase I traveled to SF for a little over a week.

The enclosure has a two pieces:

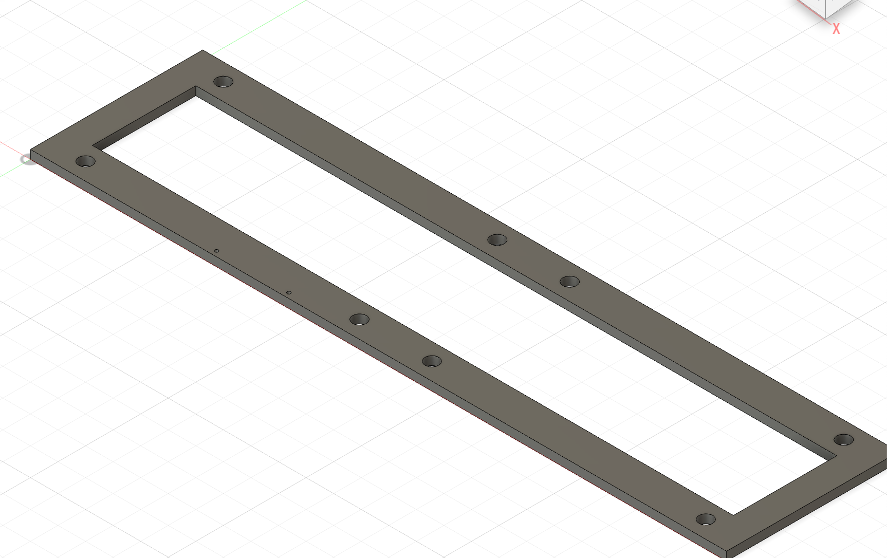
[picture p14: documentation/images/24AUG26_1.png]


a "top" piece that screws into the LED matrix with the provided screws

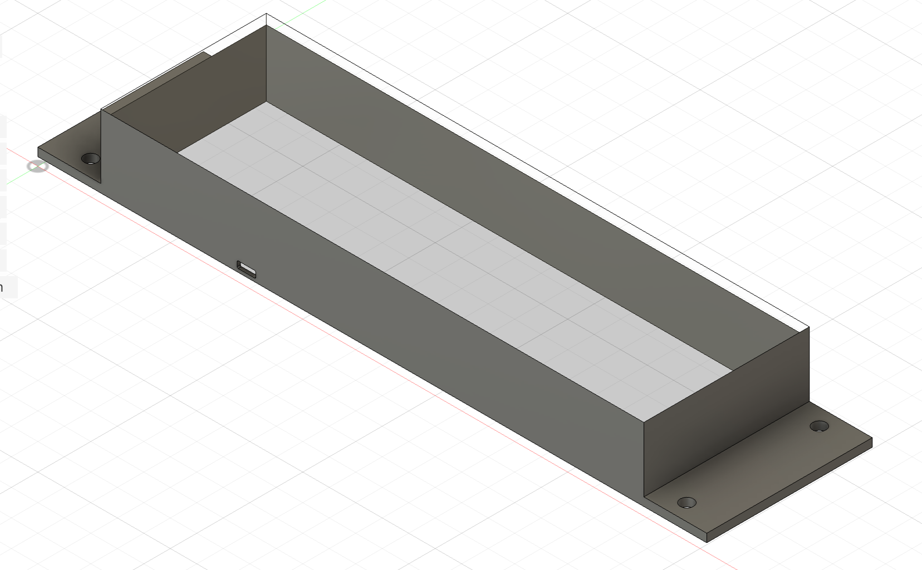
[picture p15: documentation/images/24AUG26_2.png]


a "bottom" piece that keeps the back flat and makes space for electronics. Note that this is actually closed. I just set the top layer to be see-through for visibility here.

I think the enclosure achieves the things I outlined above. It's not perfect, but it works. Below is a list of things left to address for future versions of this project:

### Things to address for v2

**PCB**

- Add POWER and GND symbols for the spade connectors that power the matrix
- Re-wire the HUB75 connector the right way
  - Maybe make the header ont he board a female header instead of a male header also
- Maybe add a button or something that you can access from outside the enclosure

**Enclosure**

- Tilt
  - When resting on a flat surface, the enclosure gets some tilt from the USB-C cable poking out of the bottom. This works well for keeping the tracker upright, but it is a little janky.
  - For future versions, it would be nice for this tilt to come form the enclosure itself rather than the cable
    - Could use some feet
    - May need to move position of the cable (depends on PCB obv)
- USB-C Port
  - May need to make the hole for it a little bigger
    - It didn't immediately work, had to make it bigger w some pliers
  - May need to change location (see above)
- Assembly
  - It's a little hard to assemble
    - Was hard to line up both pieces with the holes and each other
    - Some of it is just due to my measurements probably being a little off/not leaving enough clearance
    - I think the two-piece assembly isn't the best. May want to reconsider.
  - To fix, maybe add some clearance and consider re-designing with focus on easier assembly

**Software**

- Bluetooth control
- Return from error states more gracefully
  - One day I came back home and I saw that it was just stuck in an error. Rather than getting stuck, it should show an error message and then attempt to return to normal operation?

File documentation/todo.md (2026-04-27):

# todo
- [x] ~~Get API keys (done Mar 22)~~

- [x] ~~Set up github repo (done Mar 22)~~

- [x] ~~Research what LED matrix screen to buy (done Mar 23)~~

- [x] ~~Research if other hardware is needed (do I want to connect this to wall power? use a battery? etc) (done Mar 23)~~ 

- [x] ~~Add secrets.h~~ (done Mar 23)

- [x] ~~Read Bus and Train APIs~~ (done Mar 24)

- [x] ~~Make rough ESP32 prototype that prints bus data to command line~~ (done Mar. 31)

  - [x] ~~Print raw bus data to command line~~ (done Mar. 26)

  - [x] ~~Parse JSON response and print parsed response~~ (done Mar. 30)

  - [x] ~~Set up the parse task to handle different request types~~ (done Mar. 31)

- [x] ~~Add train data to the ESP32 prototype~~ (done apr. 9)

  - [x] ~~perform a train get request~~ (done apr. 6)
  
  - [x] ~~format predictions into countdown~~ (done apr. 9)
  
  - [x] ~~Add delay/due functionality~~ (done apr. 7)
  
- [x] Make GET request parameters into variables (rn they're hard-coded)

- [ ] Filter old predictions based on precition time stamp

- [ ] Have some sort of output when nothing is scheduled

- [x] ~~Make sure the LED matrices work~~ (done apr. 15)

- [x] Read the matrix library documentation

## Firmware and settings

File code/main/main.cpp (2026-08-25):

#include "main.h"

/**************************************************************************************
 * MACRO DEFINITIONS
 */
// defining function macros
#define STR_HELPER(x) #x
#define STR(x) STR_HELPER(x)

#define CEIL(x,y) (((x) + (y) - 1)/(y))

// building  bus URL for API calls
#define BUS_URL_ROOT        "https://www.ctabustracker.com/bustime/api/v3/"     // root of url
#define BUS_URL_KEY         "key=" BUS_TRACKER_API_KEY  // api key
#define BUS_URL_FORMAT      "&format=json"  // format of the response
#define BUS_URL_ROUTES      "&rt=" CONFIG_TRACKER_BUS_ROUTES    // routes to get info about
#define BUS_URL_STPID       "&stpid="  CONFIG_TRACKER_BUS_STPIDS  // stops to get info about
#define BUS_URL_TOP         "&top="   STR(CONFIG_TRACKER_BUS_TOP) // max number of predictions to receive
#define BUS_URL             BUS_URL_ROOT "getpredictions?" BUS_URL_KEY BUS_URL_ROUTES BUS_URL_STPID \
                            BUS_URL_TOP "&unixTime=true" BUS_URL_FORMAT

// building train URL for API calls
#define TRAIN_URL_ROOT      "http://lapi.transitchicago.com/api/1.0/"    // root of url
#define TRAIN_URL_KEY       "key=" TRAIN_TRACKER_API_KEY  // api key
#define TRAIN_URL_FORMAT    "&outputType=JSON" // format of the response
#define TRAIN_URL_MAPID     "&mapid=" CONFIG_TRACKER_TRAIN_MAPID // station to get info about
#define TRAIN_URL_MAX       "&max=" STR(CONFIG_TRACKER_TRAIN_MAX)    // max number of predictions to receive
#define TRAIN_URL           TRAIN_URL_ROOT "ttarrivals.aspx?" TRAIN_URL_KEY TRAIN_URL_MAPID \
                            TRAIN_URL_MAX TRAIN_URL_FORMAT

#define TIME_URL BUS_URL_ROOT "gettime?" BUS_URL_KEY "&unixTime=true" BUS_URL_FORMAT

// defining helpful compile-time constants
#define CONNECTION_TIMEOUT_SEC  10
#define ROWS_PER_SCREEN         3
#define BUS_COLS_PER_ROW        3
#define TRAIN_COLS_PER_ROW      2
#define NUM_BUS_SCREENS         CEIL(CONFIG_TRACKER_BUS_TOP, ROWS_PER_SCREEN)
#define NUM_TRAIN_SCREENS       CEIL(CONFIG_TRACKER_TRAIN_MAX, ROWS_PER_SCREEN)
#define BUS_PREDICTION_BIT      BIT0
#define TRAIN_PREDICTION_BIT    BIT1
#define GET_FAIL_BIT            BIT3

/**************************************************************************************
 * GLOBALS DEFINITIONS
 */
static const char *TAG = "transit-tracker";

// Global HUB75 driver instance (needed in flush callback)
static Hub75Driver *g_driver = nullptr;

// LVGL mutex for thread safety
static SemaphoreHandle_t lvgl_mutex = nullptr;

// Screen constants
Screen_t *bus_screen_array[NUM_BUS_SCREENS];
Screen_t *train_screen_array[NUM_TRAIN_SCREENS];

uint16_t curr_bus_predictions = 0;
uint16_t curr_train_predictions = 0;

EventGroupHandle_t prediction_event_group;

/**************************************************************************************
 * FUNCTION DEFINITIONS
 */
// Forward declaration
extern "C" void lvgl_ui(lv_obj_t *scr, lv_obj_t **label_array, int num_rows, int num_cols, bool train_ui);

// LVGL mutex lock/unlock helpers
static bool lvgl_lock(int timeout_ms) {
  const TickType_t timeout_ticks = (timeout_ms < 0) ? portMAX_DELAY : pdMS_TO_TICKS(timeout_ms);
  return xSemaphoreTakeRecursive(lvgl_mutex, timeout_ticks) == pdTRUE;
}

static void lvgl_unlock() { xSemaphoreGiveRecursive(lvgl_mutex); }

// LVGL display flush callback
// Called by LVGL when a screen region needs updating
static void lvgl_flush_cb(lv_display_t *disp, const lv_area_t *area, uint8_t *px_map) {
  if (g_driver == nullptr) {
    ESP_LOGE(TAG, "FLUSH: HUB75 driver is NULL!");
    lv_display_flush_ready(disp);
    return;
  }

  // Get area bounds and draw pixels
  const uint16_t x = area->x1;
  const uint16_t y = area->y1;
  const uint16_t w = area->x2 - area->x1 + 1;
  const uint16_t h = area->y2 - area->y1 + 1;

  g_driver->draw_pixels(x, y, w, h, px_map, Hub75PixelFormat::RGB565);

#ifdef CONFIG_HUB75_DOUBLE_BUFFER
  g_driver->flip_buffer();
#endif

  lv_display_flush_ready(disp);
}

// LVGL timer task - calls lv_timer_handler() periodically
static void lvgl_timer_task(void *arg) {
  ESP_LOGI(TAG, "LVGL timer task started");

  TickType_t last_wake_time = xTaskGetTickCount();

  while (1) {
    // Lock LVGL mutex
    if (lvgl_lock(10)) {
      // Calculate elapsed time and update LVGL tick (required for animations)
      TickType_t current_time = xTaskGetTickCount();
      uint32_t elapsed_ms = pdTICKS_TO_MS(current_time - last_wake_time);
      last_wake_time = current_time;
      lv_tick_inc(elapsed_ms);

      // Handle LVGL timers and tasks (triggers redraws and animations)
      uint32_t sleep_ms = lv_timer_handler();
      lvgl_unlock();

      // Ensure reasonable sleep bounds for smooth animations
      if (sleep_ms > 100) {
        sleep_ms = 100;  // Max 100ms for responsive animations
      } else if (sleep_ms < 1) {
        sleep_ms = 1;  // Min 1ms to prevent busy-wait
      }

      vTaskDelay(pdMS_TO_TICKS(sleep_ms));
    } else {
      ESP_LOGW(TAG, "Could not get LVGL lock");
      vTaskDelay(pdMS_TO_TICKS(50));
    }
  }
}


/**
 * Function that performs all the Wi-Fi set up (starting NVS, initializing TCP/IP stack,
 * creating default event loop, initializing the Wi-Fi driver. Blocks while waiting for
 * a Wi-Fi connection.)
 * @param none
 * @return ESP_OK if connection is successful, ESP_FAIL otherwise (and prints error code)
 */
esp_err_t connect_to_wifi(void) {
    esp_err_t esp_ret;
    EventGroupHandle_t wifi_event_group = xEventGroupCreate();
    
    // start nvs
    esp_ret = nvs_flash_init();
    if (esp_ret != ESP_OK) {
        if ((esp_ret == ESP_ERR_NVS_NO_FREE_PAGES) ||
            (esp_ret == ESP_ERR_NVS_NEW_VERSION_FOUND)) {
            ESP_ERROR_CHECK(nvs_flash_erase());
            esp_ret = nvs_flash_init();
        }
        if (esp_ret != ESP_OK) {
            ESP_LOGE(TAG, "Error (%d): Could not initialize NVS", esp_ret);
            return ESP_FAIL;
        }
    }

    // initialize TCP/IP stack
    esp_ret = esp_netif_init();
    if (esp_ret != ESP_OK) {
        ESP_LOGE(TAG, "Error (%d): Couldn't initialize TCP/IP stack", esp_ret);
        return ESP_FAIL;
    }

    // create default event loop
    esp_ret = esp_event_loop_create_default();
    if (esp_ret != ESP_OK) {
        ESP_LOGE(TAG, "Error (%d): Couldn't create default event loop", esp_ret);
        return ESP_FAIL;
    }

    // initialize wifi
    esp_ret = wifi_sta_init(wifi_event_group);
    if (esp_ret != ESP_OK) {
        ESP_LOGE(TAG, "Error (%d): Failed to initialize wifi", esp_ret);
        return ESP_FAIL;
    }

    // wait for connection (blocking)
    while (!wait_for_wifi(wifi_event_group, CONNECTION_TIMEOUT_SEC)) {
        ESP_LOGI(TAG, "Reinitializing Wi-Fi after a failed attempt...");
        esp_ret = wifi_sta_reconnect();
        if (esp_ret != ESP_OK) {
            ESP_LOGE(TAG, "Error (%d): Failed to connect to Wi-Fi");
            return ESP_FAIL;
        }
    }

    return ESP_OK;
}

/**
 * Updates screen labels with properly formatted train info. Predictions are in minutes,
 * and it prints the current station name in the color of the route, the destination name, and the prediction
 * (or prints DUE/DLY if train is due or delayed instead of a prediction).
 * @param destNm cJSON* corresponding to the destNm output of API
 * @param isApp cJSON* corresponding to the isApp output of API
 * @param isDly cJSON* corresponding to the isDly output of API
 * @param prdT cJSON* corresponding to the prdT output of API
 * @param arrT cJSON* corresponding to the arrT output of API
 * @param rt CSON* corresponding to the rt output of API
 * @param staNm cJSON* corresopnding to the staNm output of API
 * @param prediction_count size_t corresponding to the current total number of predictions
 * that have been processed (used to update correct label, 0 = first prediction, 1 = second, etc)
 */
esp_err_t print_train_info(cJSON *destNm, cJSON *isApp, cJSON *isDly, cJSON *prdT,
                      cJSON *arrT, cJSON *rt, cJSON *staNm, size_t prediction_count)
{
    // format train API response
    char time_to_arrival[16];
    if (strcmp(isApp->valuestring, "0") != 0) {
        // train is approaching
        snprintf(time_to_arrival, sizeof(time_to_arrival), "DUE");
    }
    else if (strcmp(isDly->valuestring, "0") != 0) {
        // train is delayed
        snprintf(time_to_arrival, sizeof(time_to_arrival), "DLY");
    }
    else {
        // train will arrive, predict when (done by converting API output to unix time)
        // and then comparing the unix time vaues with difftime
        struct tm tm_arrT;
        
        if (strptime(arrT->valuestring, "%Y-%m-%dT%T", &tm_arrT) == NULL) {
            ESP_LOGE(TAG, "Couldn't change arrT to tm struct");
            return ESP_FAIL;
        }
        struct tm tm_prdT;
        
        if (strptime(prdT->valuestring, "%Y-%m-%dT%T", &tm_prdT) == NULL) {
            ESP_LOGE(TAG, "Couldn't change prdT to tm struct");
            return ESP_FAIL;
        }

        time_t unix_arrT;
        time_t unix_prdT;
        unix_arrT = mktime(&tm_arrT);
        unix_prdT = mktime(&tm_prdT);
        
        if ((unix_arrT == -1) || (unix_prdT == -1)) {
            ESP_LOGE(TAG, "Couldn't change arrT or prdT to unix time");
            return ESP_FAIL;
        }
        int diff = difftime(unix_arrT, unix_prdT)/60;
        
        if (diff < 0) {
            ESP_LOGE(TAG, "Error, train prediction is negative (%.2f)", diff);
            return ESP_FAIL;
        }
        snprintf(time_to_arrival, sizeof(time_to_arrival), "%d", diff);
    }

    // Setting color codes based on CTA standard
    char sta_and_dest[128];
    for (int i = 0; i < NUM_ROUTES; i++) {
        if (strcmp(rt->valuestring, route_colors[i].route) == 0) {
            snprintf(sta_and_dest, sizeof(sta_and_dest), "%s %s#: %s", route_colors[i].color_hex,
                     staNm->valuestring, destNm->valuestring);
        }
    }

    // print the formatted response to the labels
    size_t screen_idx = prediction_count / ROWS_PER_SCREEN;
    size_t label_idx = (prediction_count % ROWS_PER_SCREEN) * TRAIN_COLS_PER_ROW;

    Screen_t *curr_screen = train_screen_array[screen_idx];
    if (lvgl_lock(portMAX_DELAY)) {
        lv_label_set_text(curr_screen->label_array[label_idx], sta_and_dest);
        lv_label_set_text(curr_screen->label_array[label_idx+1], time_to_arrival);
        lvgl_unlock();
    }
    printf("Prediction: %s, %s - %s\n", rt->valuestring, destNm->valuestring, time_to_arrival);
    return ESP_OK;
}

/**
 * Task that parses JSON data from queue passed into pvParameters. It will parse bus and train
 * predictions and print them on the correct screen labels. It will also parse time requests 
 * and print those to the console.
 * @param pvParameters: expects handle to a queue of char* buffers
 */
void vParseAPIResponseTask(void *pvParameters)
{
    QueueHandle_t response_queue = (QueueHandle_t)pvParameters;
    BaseType_t ret;
    esp_err_t esp_ret;
    for (;;) {
        // get data from response queue
        QueueData_t queue_data;
        ret = xQueueReceive(response_queue, &queue_data, portMAX_DELAY);

        // if data was received from the queue successfully, process it
        if (ret == pdPASS) {
            ESP_LOGI(TAG, "Received a buffer, parsing...");

            // setting up JSON struct
            cJSON *json;
            json = cJSON_Parse(queue_data.buffer);
            if (json == NULL) {
                ESP_LOGE(TAG, "Failed to parse JSON response");
            }

            if (queue_data.response_type == e_bus_prediction){
                // getting predictions from JSON response
                cJSON *response;    // top level item
                cJSON *predictions; // predictions come in an array item with name "prd"
                cJSON *prediction;  // cJSON level for each individual prediction
                response = cJSON_GetObjectItem(json, "bustime-response");
                predictions = cJSON_GetObjectItem(response, "prd");

                // Since predictions come in an array, must iterate through each prediction
                // in predictions
                uint32_t prediction_count = 0;
                int screen_idx = 0;
                cJSON_ArrayForEach(prediction, predictions) {
                    cJSON *rt = cJSON_GetObjectItemCaseSensitive(prediction, "rtdd");
                    cJSON *prdctdn = cJSON_GetObjectItemCaseSensitive(prediction, "prdctdn");
                    cJSON *stpnm = cJSON_GetObjectItemCaseSensitive(prediction, "stpnm");
                    cJSON *rtdir = cJSON_GetObjectItemCaseSensitive(prediction, "rtdir");
                    if ((rt == NULL) || (prdctdn == NULL) || (stpnm == NULL) || (rtdir == NULL)) {
                        ESP_LOGE(TAG, "Couldn't parse bus prediction");
                    }
                    else {
                        // current screen to update
                        Screen_t *curr_screen = bus_screen_array[screen_idx];
                        // label_idx basically just says what row we are currently updating 
                        size_t label_idx = (prediction_count % ROWS_PER_SCREEN) * 3;

                        // combining direction and stop data for the middle label
                        char dir_and_stop[128];
                        if (strcmp(rtdir->valuestring, "Northbound") == 0) {
                            snprintf(dir_and_stop, sizeof(dir_and_stop), "N: %s", stpnm->valuestring);
                        } else if (strcmp(rtdir->valuestring, "Southbound") == 0) {
                            snprintf(dir_and_stop, sizeof(dir_and_stop), "S: %s", stpnm->valuestring);
                        } else if (strcmp(rtdir->valuestring, "Eastbound") == 0) {
                            snprintf(dir_and_stop, sizeof(dir_and_stop), "E: %s", stpnm->valuestring);
                        } else {
                            snprintf(dir_and_stop, sizeof(dir_and_stop), "W: %s", stpnm->valuestring);
                        }

                        // setting the text for the labels on the screen
                        if (label_idx + 2 < ROWS_PER_SCREEN * BUS_COLS_PER_ROW){
                            if (lvgl_lock(portMAX_DELAY)) {
                                lv_label_set_text(curr_screen->label_array[label_idx], rt->valuestring);
                                lv_label_set_text(curr_screen->label_array[label_idx+1], dir_and_stop);
                                lv_label_set_text(curr_screen->label_array[label_idx+2], prdctdn->valuestring);
                                lvgl_unlock();
                            } else {
                                ESP_LOGW(TAG, "Skipped label update bc lock failed");
                            }
                        } 
                        printf("Prediction: %s - %s, %s\n", rt->valuestring, stpnm->valuestring, prdctdn->valuestring);
                    }

                    prediction_count++;
                    if (prediction_count % ROWS_PER_SCREEN == 0)
                        screen_idx++;
                }

                curr_bus_predictions = prediction_count;
                xEventGroupSetBits(prediction_event_group, BUS_PREDICTION_BIT);
            }
            else if (queue_data.response_type == e_train_prediction) {
                // getting train prediction from JSON reponse
                cJSON *response;
                cJSON *predictions;
                cJSON *prediction;
                response = cJSON_GetObjectItem(json, "ctatt");
                predictions = cJSON_GetObjectItem(response, "eta");

                size_t prediction_count = 0;
                cJSON_ArrayForEach(prediction, predictions) {
                    cJSON *destNm = cJSON_GetObjectItem(prediction, "destNm");
                    cJSON *isApp = cJSON_GetObjectItem(prediction, "isApp");
                    cJSON *isDly = cJSON_GetObjectItem(prediction, "isDly");
                    cJSON *prdT = cJSON_GetObjectItem(prediction, "prdT");
                    cJSON *arrT = cJSON_GetObjectItem(prediction, "arrT");
                    cJSON *rt = cJSON_GetObjectItem(prediction, "rt");
                    cJSON *staNm = cJSON_GetObjectItem(prediction, "staNm");

                    if ((destNm == NULL) || (isApp == NULL) || (isDly == NULL) || (staNm == NULL) ||
                        (prdT == NULL) || (arrT == NULL) || (destNm == NULL) || (rt == NULL)) {

                        ESP_LOGE(TAG, "Couldn't parse train prediction");
                    }
                    else {
                        esp_ret = print_train_info(destNm, isApp, isDly, prdT, arrT, rt, staNm, prediction_count);
                        if (esp_ret != ESP_OK) {    // if it fails, this prediction won't be printed, so decrease prediction count
                            prediction_count--;
                        }
                    }
                    
                    prediction_count++;
                }
                curr_train_predictions = prediction_count;
                xEventGroupSetBits(prediction_event_group, TRAIN_PREDICTION_BIT);
            }
            
            cJSON_Delete(json);
            free(queue_data.buffer);
        }
        // if data was not received successfully, output an error
        else {
            ESP_LOGI(TAG, "Couldn't receive buffer (queue empty)? %s", ret);
        }
        ESP_LOGI(TAG, "Leaving parsing task");
        ESP_LOGI(TAG, "Parse task high water mark: %lu", uxTaskGetStackHighWaterMark(NULL));
    }    
}
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
extern "C" void app_main(void)
{
    esp_err_t esp_ret;
    BaseType_t rtos_ret;
    lv_display_t *disp;

    prediction_event_group = xEventGroupCreate();
    Hub75Config config = getMenuConfigSettings();   // Load configuration from menuconfig
    static Hub75Driver driver(config);  // Create and initialize HUB75 driver
    g_driver = &driver;


    ESP_LOGI(TAG, "Transit tracker starting...");


    ESP_LOGI(TAG, "Configuration:");
    ESP_LOGI(TAG, "  Panel: %dx%d pixels", config.panel_width, config.panel_height);
    ESP_LOGI(TAG, "  Double buffering: %s", config.double_buffer ? "ENABLED" : "DISABLED");

    esp_ret = hub75_begin(driver, config);
    if (esp_ret != ESP_OK) {
        ESP_LOGE(TAG, "HUB75 driver initialization failed. Aborting.");
        abort();
    }

    esp_ret = lvgl_init(driver, &disp);
    if (esp_ret != ESP_OK) {
        ESP_LOGE(TAG, "LVGL initialization failed. Aborting.");
        abort();
    }

    // Creating screens
    create_screens(bus_screen_array, NUM_BUS_SCREENS, disp, false);
    create_screens(train_screen_array, NUM_TRAIN_SCREENS, disp, true);
    
    esp_ret = connect_to_wifi();
    if (esp_ret != ESP_OK) {
        ESP_LOGE(TAG, "Wi-Fi connection failed. Aborting.");
        abort();
    }

    QueueHandle_t schedule_queue = xQueueCreate(3, sizeof(QueueData_t));

    rtos_ret = xTaskCreate(vPerformGetRequestTask, "Perform GET Request Task", 4096, (void *)schedule_queue, 3, NULL);
    if (rtos_ret != pdPASS) {
        ESP_LOGE(TAG, "Failed to create GET request task!");
        abort();
    }

    rtos_ret = xTaskCreate(lvgl_timer_task, "lvgl timer task", 4096, NULL, 4, NULL);
    if (rtos_ret != pdPASS) {
        ESP_LOGE(TAG, "Failed to create LVGL timer task!");
        abort();
    }

    ESP_LOGI(TAG, "LVGL running, demo UI displayed");

    // Setting messages for GET request task
    QueueData_t bus_msg;
    bus_msg.url = BUS_URL;
    bus_msg.response_type = e_bus_prediction;

    QueueData_t train_msg;
    train_msg.url = TRAIN_URL;
    train_msg.response_type = e_train_prediction;
    
    lv_screen_load(bus_screen_array[0]->screen);

    for (;;) {

        esp_ret = run_prediction_cycle(e_bus_prediction, schedule_queue, bus_msg, &curr_bus_predictions, 8000);
        if (esp_ret != ESP_OK) {
            lv_obj_t **label = bus_screen_array[0]->label_array;

            // Setting error text and clearing rest of screen
            lv_label_set_text(label[0], "Bus prediction failed...");
            for (int i = 1; i < BUS_COLS_PER_ROW * ROWS_PER_SCREEN; i++) {
                lv_label_set_text(label[i], "");
            }

            lv_screen_load(bus_screen_array[0]->screen);
            vTaskDelay(pdMS_TO_TICKS(1000));
        }

        esp_ret = run_prediction_cycle(e_train_prediction, schedule_queue, train_msg, &curr_train_predictions, 8000);
        if (esp_ret != ESP_OK) {
            lv_obj_t **label = train_screen_array[0]->label_array;
            
            // Setting error text and clearing rest of screen
            lv_label_set_text(label[0], "Train prediction failed...");
            for (int i = 1; i < TRAIN_COLS_PER_ROW * ROWS_PER_SCREEN; i++) {
                lv_label_set_text(label[i], "");
            }

            lv_screen_load(train_screen_array[0]->screen);
            vTaskDelay(pdMS_TO_TICKS(1000));
        }
    }
}

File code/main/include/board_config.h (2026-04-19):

// SPDX-FileCopyrightText: 2025 Stuart Parmenter
// SPDX-License-Identifier: MIT

// @file board_config.h
// @brief Helper to load menuconfig settings into Hub75Config

#pragma once

#include "hub75.h"
#include "sdkconfig.h"
#include <esp_log.h>
#include <cstdio>

static const char *const TAG_CONFIG = "board_config";

// Load configuration from menuconfig (CONFIG_* defines)
static inline Hub75Config getMenuConfigSettings() {
  Hub75Config config = {};

  // Panel dimensions
  config.panel_width = CONFIG_HUB75_PANEL_WIDTH;
  config.panel_height = CONFIG_HUB75_PANEL_HEIGHT;

  // Scan wiring (scan rate is determined automatically from panel_height)
#if defined(CONFIG_HUB75_WIRING_STANDARD)
  config.scan_wiring = Hub75ScanWiring::STANDARD_TWO_SCAN;
#elif defined(CONFIG_HUB75_WIRING_SCAN_1_4_16PX)
  config.scan_wiring = Hub75ScanWiring::SCAN_1_4_16PX_HIGH;
#elif defined(CONFIG_HUB75_WIRING_SCAN_1_8_32PX)
  config.scan_wiring = Hub75ScanWiring::SCAN_1_8_32PX_HIGH;
#elif defined(CONFIG_HUB75_WIRING_SCAN_1_8_40PX)
  config.scan_wiring = Hub75ScanWiring::SCAN_1_8_40PX_HIGH;
#elif defined(CONFIG_HUB75_WIRING_SCAN_1_8_64PX)
  config.scan_wiring = Hub75ScanWiring::SCAN_1_8_64PX_HIGH;
#endif

  // Shift driver
#if defined(CONFIG_HUB75_DRIVER_GENERIC)
  config.shift_driver = Hub75ShiftDriver::GENERIC;
#elif defined(CONFIG_HUB75_DRIVER_FM6126A)
  config.shift_driver = Hub75ShiftDriver::FM6126A;
#elif defined(CONFIG_HUB75_DRIVER_FM6124)
  config.shift_driver = Hub75ShiftDriver::FM6124;
#elif defined(CONFIG_HUB75_DRIVER_MBI5124)
  config.shift_driver = Hub75ShiftDriver::MBI5124;
#elif defined(CONFIG_HUB75_DRIVER_DP3246)
  config.shift_driver = Hub75ShiftDriver::DP3246;
#endif

  // Pin configuration (board preset or custom)
#if defined(CONFIG_HUB75_BOARD_ADAFRUIT_MATRIX_PORTAL_S3)
  // Adafruit Matrix Portal S3
  config.pins.r1 = 42;
  config.pins.g1 = 41;
  config.pins.b1 = 40;
  config.pins.r2 = 38;
  config.pins.g2 = 39;
  config.pins.b2 = 37;
  config.pins.a = 45;
  config.pins.b = 36;
  config.pins.c = 48;
  config.pins.d = 35;
  config.pins.e = 21;
  config.pins.lat = 47;
  config.pins.oe = 14;
  config.pins.clk = 2;
  ESP_LOGI(TAG_CONFIG, "Board preset: Adafruit Matrix Portal S3");

#elif defined(CONFIG_HUB75_BOARD_APOLLO_M1_REV4)
  // Apollo Automation M1 Rev4 (same pins as Adafruit)
  config.pins.r1 = 42;
  config.pins.g1 = 41;
  config.pins.b1 = 40;
  config.pins.r2 = 38;
  config.pins.g2 = 39;
  config.pins.b2 = 37;
  config.pins.a = 45;
  config.pins.b = 36;
  config.pins.c = 48;
  config.pins.d = 35;
  config.pins.e = 21;
  config.pins.lat = 47;
  config.pins.oe = 14;
  config.pins.clk = 2;
  ESP_LOGI(TAG_CONFIG, "Board preset: Apollo Automation M1 Rev4");

#elif defined(CONFIG_HUB75_BOARD_APOLLO_M1_REV6)
  // Apollo Automation M1 Rev6
  config.pins.r1 = 1;
  config.pins.g1 = 5;
  config.pins.b1 = 6;
  config.pins.r2 = 7;
  config.pins.g2 = 13;
  config.pins.b2 = 9;
  config.pins.a = 16;
  config.pins.b = 48;
  config.pins.c = 47;
  config.pins.d = 21;
  config.pins.e = 38;
  config.pins.lat = 8;
  config.pins.oe = 4;
  config.pins.clk = 18;
  ESP_LOGI(TAG_CONFIG, "Board preset: Apollo Automation M1 Rev6");

#elif defined(CONFIG_HUB75_BOARD_HUIDU_HD_WF2)
  // Huidu HD-WF2
  config.pins.r1 = 2;
  config.pins.g1 = 6;
  config.pins.b1 = 10;
  config.pins.r2 = 3;
  config.pins.g2 = 7;
  config.pins.b2 = 11;
  config.pins.a = 39;
  config.pins.b = 38;
  config.pins.c = 37;
  config.pins.d = 36;
  config.pins.e = 21;  // TODO: Confirm E pin assignment
  config.pins.lat = 33;
  config.pins.oe = 35;
  config.pins.clk = 34;
  ESP_LOGI(TAG_CONFIG, "Board preset: Huidu HD-WF2");

#elif defined(CONFIG_HUB75_BOARD_GENERIC_S3)
  // Generic ESP32-S3 (sequential GPIO 1-14)
  config.pins.r1 = 1;
  config.pins.g1 = 2;
  config.pins.b1 = 3;
  config.pins.r2 = 4;
  config.pins.g2 = 5;
  config.pins.b2 = 6;
  config.pins.a = 7;
  config.pins.b = 8;
  config.pins.c = 9;
  config.pins.d = 10;
  config.pins.e = 11;
  config.pins.lat = 12;
  config.pins.oe = 13;
  config.pins.clk = 14;
  ESP_LOGI(TAG_CONFIG, "Board preset: Generic ESP32-S3");

#else  // CONFIG_HUB75_BOARD_CUSTOM
  // Custom pin configuration from menuconfig
  config.pins.r1 = CONFIG_HUB75_PIN_R1;
  config.pins.g1 = CONFIG_HUB75_PIN_G1;
  config.pins.b1 = CONFIG_HUB75_PIN_B1;
  config.pins.r2 = CONFIG_HUB75_PIN_R2;
  config.pins.g2 = CONFIG_HUB75_PIN_G2;
  config.pins.b2 = CONFIG_HUB75_PIN_B2;
  config.pins.a = CONFIG_HUB75_PIN_A;
  config.pins.b = CONFIG_HUB75_PIN_B;
  config.pins.c = CONFIG_HUB75_PIN_C;
  config.pins.d = CONFIG_HUB75_PIN_D;
  config.pins.e = CONFIG_HUB75_PIN_E;
  config.pins.lat = CONFIG_HUB75_PIN_LAT;
  config.pins.oe = CONFIG_HUB75_PIN_OE;
  config.pins.clk = CONFIG_HUB75_PIN_CLK;
  ESP_LOGI(TAG_CONFIG, "Board preset: Custom");
#endif

  // Multi-panel layout
  config.layout_rows = CONFIG_HUB75_LAYOUT_ROWS;
  config.layout_cols = CONFIG_HUB75_LAYOUT_COLS;
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

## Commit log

2026-04-09 Updating print_train_info function to format train arrival times into a minute countdown
2026-04-16 Adding documentation of first day using LED matrices
2026-04-19 Setting up project to work with hub75 dma library and lvgl
2026-04-24 Adding Kconfig file (right now just useful for buses), adding screen-switching functionality for bus predictions
2026-05-01 Adding run_prediction_cycle() to simplify app_main flow, adding error handling in app_main and print_train_info()
    [main.cpp]
2026-05-02 Adding GET_FAIL_BIT for smoother GET request error handling, optimizing label time, and clearing old labels when displaying GET errors
    [main.cpp]
2026-08-25 Updating BOM, adding gerber files
2026-08-25 Adding enclosure files
    [Transit Tracker Enclosure Hollow Part.3mf, Transit Tracker Enclosure Thin Part.3mf]
